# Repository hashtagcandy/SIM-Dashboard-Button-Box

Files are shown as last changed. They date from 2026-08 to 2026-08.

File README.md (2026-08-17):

# ETS2 Sim Button Box

Custom Euro Truck Simulator 2 button box built around a Raspberry Pi Pico H (RP2040).

## Overview

- **Input**: 6x6 switch matrix (12 GPIO) -> ~31 logical controls
- **Output**: 23 indicator LEDs driven by 3x 74HC595 shift registers
- **Interface**: USB Keyboard HID to Windows, bound to ETS2 actions
- **Firmware**: Custom Arduino USB keyboard HID sketch

## Hardware inventory

| Hardware | Qty | Use |
|---|---|---|
| Raspberry Pi Pico H (RP2040) | 1 | Main controller (chosen brain) |
| SmartElex 74HC595 shift register breakout | 3 | LED drivers (24 outputs, 23 used) |
| Pro Micro (Type C, ATmega32U4) | 1 | Spare / test board |
| 3-position rotary selector | 2 | Wipers + Lights |
| Toggle switch | 6 | High beam, beacon, hazard, diff lock, axle, cruise |
| Push/pull switch | 2 | Parking brake, trailer brake |
| Rocker switch | 3 | Windows L/R, cruise speed |
| Latching push button | 3 | Trailer attach, dash mode, audio prev |
| Momentary push button | 5 | Horns, activate, wipers back |
| Ignition key switch | 1 | ACC / ON / START |
| Radio knob (encoder) | 1 | Volume, next favourite |

## Repo layout

```
SOUL.md        Project spec, GPIO map, matrix map, LED map, rules
prerequisites/ Planning docs: key mapping, layout designs, measurements
firmware/      Arduino sketches (Pico H)
docs/          Wiring diagrams, ETS2 bindings, measurement notes
```

## Prerequisites (planning stage)

| File | What it is |
|---|---|
| `prerequisites/01 - key to physical button mapping.md` | All 29 ETS2 functions mapped to physical controls + matrix positions |
| `prerequisites/02 - mapping table.csv` | Same mapping as CSV quick reference |
| `prerequisites/03 - panel layout design.md` | Design principles, LED placement, hole sizes |
| `prerequisites/04 - panel layout diagram.svg` | First layout visual (superseded by A/B/C) |
| `prerequisites/05 - layout A - classic dash.svg` | Layout option A (ignition bottom-left) |
| `prerequisites/06 - layout B - split console.svg` | Layout option B (ignition bottom-right) |
| `prerequisites/07 - layout C - cockpit cluster.svg` | Layout option C (ignition bottom-left) |
| `prerequisites/08 - layout comparison.md` | Compares the three layouts, recommendation |
| `prerequisites/09 - shopping list and BOM.md` | Bill of materials: owned / to buy / tools |
| `prerequisites/10 - keyboard key inventory.md` | Key list, counts, conflicts to fix |
| `prerequisites/11 - matrix design.md` | 6x6 matrix wiring design, scan scheme, ignition re-map |
| `prerequisites/12 - box measurements.md` | Panel size, hole sizes, all hole center coordinates (mm) |
| `prerequisites/13 - drilling template.svg` | Printable 1:1 drilling template with every hole |

## Current status

- [x] Key mapping proposed (29 functions -> physical controls)
- [x] Three panel layout options generated (A/B/C)
- [x] Matrix design drafted (scan scheme, wiring, ignition re-map approved)
- [x] Box measurements + 1:1 drilling template generated (650 x 342 mm panel)
- [ ] Layout chosen by user
- [ ] Panel size / enclosure confirmed
- [ ] Selector & ignition contacts measured with multimeter
- [ ] Firmware development

## Development order

1. USB keyboard test
2. One direct switch
3. 2x2 / four-switch matrix
4. Momentary vs toggle behavior
5. Three-position selector measurement and test
6. Full 6x6 matrix
7. One 74HC595 + 8 LEDs
8. Three 74HC595 + all 23 LEDs
9. Final ETS2 key map
10. Permanent wiring and enclosure

Read `SOUL.md` before changing hardware or firmware. It is the source of truth for pin maps and behavior rules.

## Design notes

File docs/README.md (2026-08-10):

# docs/

Documentation that grows with the project.

Planned:
- `wiring.md` — physical wiring, harness, enclosure notes
- `ets2-bindings.md` — final ETS2 Controls menu key assignments
- `selector-measurements.md` — multimeter results for 3-position selectors and ignition key
- `led-map.md` — final LED numbering / labels once confirmed

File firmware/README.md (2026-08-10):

# firmware/

Arduino sketches for the Raspberry Pi Pico H (RP2040).

Planned sketches, in development order:

1. `usb_keyboard_test/` — verify USB HID enumeration and key output
2. `direct_switch/` — one direct switch (GP2 -> switch -> GND)
3. `matrix_test/` — 2x2 then 6x6 matrix scanning
4. `button_box/` — full firmware: matrix + behaviors + LED chain

Each sketch is a normal Arduino `.ino` folder.

Board setup in Arduino IDE:
- Board: Raspberry Pi Pico (via arduino-pico core: https://github.com/earlephilhower/arduino-pico)
- USB stack: "Pico SDK" (default) — Keyboard works out of the box

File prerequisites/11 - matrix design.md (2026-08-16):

# ETS2 Button Box — Switch Matrix Design

How the 6x6 matrix is wired and scanned. This is the wiring-level design
that turns the logical map (file 01/02) into physical wires on the Pico.

Status: PROPOSAL — no soldering yet. Contains one re-map decision that
needs user approval (section 4).

---

## 1. Scan scheme (how firmware reads switches)

- 6 row GPIO (GP2-GP7) configured as OUTPUT.
- 6 column GPIO (GP8-GP13) configured as INPUT_PULLUP.
- Firmware drives ONE row LOW at a time, reads all 6 columns.
- A closed switch connects row (LOW) to column -> column reads LOW = pressed.
- An open switch leaves the column HIGH (internal pull-up) = not pressed.
- Full matrix scan = 6 row activations x 6 column reads = 36 samples.
- No external pull-up resistors needed: Pico internal pull-ups (~50k ohm)
  are sufficient for a switch matrix.
- Debounce in firmware: re-read after 15-20 ms before accepting a change.

```
          COLUMNS (GP8..GP13, INPUT_PULLUP, LOW = pressed)
          C1    C2    C3    C4    C5    C6
         GP8   GP9   GP10  GP11  GP12  GP13
        +-----+-----+-----+-----+-----+-----+
R1 GP2  | W1  | W2  | W3  | L1  | L2  | L3  |  selectors (3-pos)
R2 GP3  | HB  | BEA | HAZ | DIF | AXL | CRU |  6 toggles
R3 GP4  | PK  | TRL | ATT | NXT | PRV | HRN |  push/pull + latching
R4 GP5  | AH  | LH  | DSH | ACT | WLU | WLD |  momentaries + rocker 1
R5 GP6  | WRU | WRD | CR+ | CR- | INF | SP  |  rocker 2 + cruise + infomaint
R6 GP7  | ST  | ACC | ON  | RAD+| RAD-| RDP |  ignition + radio
        +-----+-----+-----+-----+-----+-----+
        ROWS = OUTPUT, driven LOW one at a time
```

Legend:

| Label | Function | Key | Label | Function | Key |
|---|---|---|---|---|---|
| W1-3 | Wipers pos 1/2/3 | P | WRU | Open Right Window | W |
| L1-3 | Light pos 1/2/3 | L | WRD | Close Right Window | S |
| HB | High Beam | K | CR+ | Cruise speed + | = |
| BEA | Beacon | U | CR- | Cruise speed - | - |
| HAZ | Hazard | F | INF | Infomaint display | G |
| DIF | Diff Lock | D | ST | Ignition START | E |
| AXL | Lift/Drop Axle | J | ACC | Ignition ACC | Shift+E |
| CRU | Cruise Control | C | ON | Ignition ON | E |
| PK | Parking Brake | SPACE | RAD+ | Volume Up | + |
| TRL | Trailer Brake | 7 | RAD- | Volume Down | 8 |
| ATT | Trailer Attach | T | RDP | pause/play | 9 |
| NXT | Audio Next | N | SP | spare | - |
| PRV | Audio Previous | 0 | | | |
| HRN | Horn | H | | | |
| AH | Air Horn | V | | | |
| LH | Light Horn | B | | | |
| DSH | Dashboard Mode | I | | | |
| ACT | Activate | ENTER | | | |
| WLU | Open Left Window | Q | | | |
| WLD | Close Left Window | A | | | |

Keys shown are the RESOLVED map from file 10 (conflicts already fixed).

---

## 2. Wiring per control type

Each switch is wired as: ROW wire -> one lug, COLUMN wire -> other lug.

| Control | Lugs to use | Wiring |
|---|---|---|
| Toggle switch | 2 (common + ON lug) | common -> row, ON lug -> column |
| Push/pull switch | 2 | one side -> row, other side -> column |
| Momentary button | 2 | one terminal -> row, other -> column |
| Latching button | 2 | one terminal -> row, other -> column |
| Rocker (center-off) | 3 | common -> row, UP lug -> column A, DOWN lug -> column B |
| 3-position selector | 4 | common -> row, 3 state lugs -> 3 columns (MUST measure first) |
| EC11 encoder | 5 | common -> row, A -> column CW, B -> column CCW, push -> column |
| Ignition key | 4+ | common (B) -> row, ACC -> column, ON/IGN -> column, ST -> column (MUST measure first) |

### Encoder detail (EC11)

Typical EC11 has 5 pins: A, B, C (common), plus 2 for the push switch.

```
EC11            Matrix
A    ---------> column (CW detent)
B    ---------> column (CCW detent)
C    ---------> row (shared)
push ---------> column (tap on press)
```

Firmware decodes quadrature (A/B order) to decide CW vs CCW, one key tap
per detent. The push is just another switch on the same row.

### Selector detail

Both 3-position selectors occupy one full row each:

```
Selector (4 terminals)          Matrix
common lug  ----------------> R1
state lug 1 (position 1) ----> C1 / C4
state lug 2 (position 2) ----> C2 / C5
state lug 3 (position 3) ----> C3 / C6
```

Wiper selector: R1C1/R1C2/R1C3. Light selector: R1C4/R1C5/R1C6.

CONTACTS MUST BE MEASURED WITH A MULTIMETER — terminal numbers alone do
not tell you which lug is common or which is position 1/2/3.

---

## 3. Wire plan / color code

Keep 12 matrix wires traceable:

| Wire | Color | Notes |
|---|---|---|
| Rows R1-R6 | RED | tag each wire R1..R6 (heat-shrink label or tape) |
| Columns C1-C6 | BLUE | tag each wire C1..C6 |
| Common GND | BLACK | not used by matrix itself |

Each switch gets exactly two wires: one red (to its row), one blue (to
its column). Multi-position controls (rockers, selectors, encoders,
ignition) share one red wire on the common lug and one blue per column.

Wiring groups (nice for routing):

| Row | Controls sharing the row wire |
|---|---|
| R1 | Wiper selector common + Light selector common |
| R2 | 6 toggle commons |
| R3 | 2 push/pull + 3 latching + horn |
| R4 | 3 momentaries + activate + rocker 1 common |
| R5 | rocker 2 common + cruise encoder common + infomaint |
| R6 | ignition common + radio encoder common |

---

## 4. RE-MAP DECISION — ignition key needs one row (PENDING APPROVAL)

PROBLEM: the current mapping (files 01/02) puts Ignition ACC and ON on
row 5 but START on row 6. A typical ignition key switch has ONE common
lug (Battery). ACC, ON and START all share it, so they must all sit on
the SAME row. Splitting them across R5 and R6 is not physically wireable
with a single-common key.

FIX: move the whole ignition key to row 6, and slide the radio encoder
over to make room. Infomaint moves up to row 5's freed space.

| Position | OLD mapping | NEW mapping |
|---|---|---|
| R5C1 | Rocker 2 up | Rocker 2 up (unchanged) |
| R5C2 | Rocker 2 down | Rocker 2 down (unchanged) |
| R5C3 | Cruise CW | Cruise CW (unchanged) |
| R5C4 | Cruise CCW | Cruise CCW (unchanged) |
| R5C5 | Ignition ACC | **Infomaint** (moved from R6C5) |
| R5C6 | Ignition ON | **spare** (moved from R6C6) |
| R6C1 | Ignition START | Ignition START (unchanged) |
| R6C2 | Radio CW | **Ignition ACC** (moved from R5C5) |
| R6C3 | Radio CCW | **Ignition ON** (moved from R5C6) |
| R6C4 | Radio push | **Radio CW** (moved from R6C2) |
| R6C5 | Infomaint | **Radio CCW** (moved from R6C3) |
| R6C6 | spare | **Radio push** (moved from R6C4) |

Result: ignition = R6C1 (ST) / R6C2 (ACC) / R6C3 (ON), all sharing row 6.
Radio = R6C4/C5/C6, also sharing row 6. Rocker 2 + cruise + infomaint
keep row 5 to themselves. All 36 positions still used, zero new hardware.

If the multimeter later shows the ignition key has SEPARATE commons per
position (rare), the old split could work — but plan for single-common.

IF APPROVED: update `02 - mapping table.csv`, the tables in
`01 - key to physical button mapping.md`, and SOUL.md matrix map together.

---

## 5. Test plan (matrix bring-up)

1. Breadboard a 2x2 mini matrix (2 rows, 2 cols, 4 momentary buttons).
   Verify scan: press each button, confirm correct R/C detected.
2. Test simultaneous presses on the mini matrix (ghosting check).
   Matrix diodes were skipped by decision — confirm no ghosting at 2x2.
3. Build the full 6x6 on breadboard with all switch types (toggle,
   push/pull, rocker, latching, momentary, selectors, encoders, ignition).
4. Test every one of the 36 positions individually (LED or serial print).
5. Test multi-press patterns that would have ghosted before wiring permanent.
6. If ghosting appears: add one 1N4148 diode per switch (36 max), cathode
   toward the column.

---

## 6. Open questions before wiring

1. Ignition key contact layout — single common or separate per position?
   Multimeter: find common, then map ACC/ON/START lugs.
2. Selector contact layout — which lug is common, which is pos 1/2/3?
   Multimeter on all 4 lugs in all 3 positions.
3. Rocker switch type — confirm 3-terminal center-off (common + up + down).
4. EC11 encoder pinout — confirm A/B/common/push pins on the actual part.

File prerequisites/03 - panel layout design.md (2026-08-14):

# ETS2 Button Box — Panel Layout Design (v1 PROPOSAL)

Reference: prerequisites/01 - key to physical button mapping.md

## 1. Design principles

1. Group by truck function: lights together, brakes together, audio together.
2. Frequent / emergency controls closest to the user (front edge of panel):
   horns + activate.
3. Parking brake gets a prominent position — it is the most-grabbed control
   in a truck.
4. Every stateful control gets an LED right next to it (state at a glance).
5. 3-position selectors get a 3-LED position strip, like a real dash indicator.
6. Ignition key sits in a corner — the "start of the day" control, away from
   controls you touch while driving.

## 2. Default panel size assumption

Landscape panel, approx 300 x 170 mm (can be resized — nothing is cut yet).

Controls are laid out in 6 horizontal rows. Row 5 (momentary buttons) is the
front edge (closest to the user).

## 3. The layout (driver's view, top = far edge)

```
+------------------------------------------------------------------+
|  [IGN]    [WIPER  o o o]   [LIGHT  o o o]             [RADIO]   |
|  KEY      0  1  2           0  1  2                              |
|                                                                  |
|   o   o   o       o   o   o                                      |
|  [HB] [BEA] [HAZ] | [DIFF] [AXLE] [CRUISE]   <- 6 toggles       |
|                                                                  |
|   o                    o                                         |
|  [PARK BRAKE]       [TRAILER BRAKE]          <- 2 push/pull      |
|    (pull handle)      (pull handle)                              |
|                                                                  |
|  [WIN L]   [WIN R]   [CRUISE +/-]            <- 3 rockers       |
|   up/down   up/down   inc/dec                                    |
|                                                                  |
|   o   o   o       o   o                                          |
|  [HORN] [AIR] [LT HORN]  [ACT] [WIPER BACK]  <- 5 momentary     |
|                                                                  |
|   o   o   o                                                      |
|  [TRAILER ATT] [DASH MODE] [AUD PREV]        <- 3 latching      |
|                                                                  |
|                 ^                                                |
|                 front edge (closest to user)                     |
+------------------------------------------------------------------+
```

o = indicator LED next to the control

## 4. LED placement

| LED | Location |
|---|---|
| Wiper pos 1/2/3 | 3-LED strip directly above wiper selector |
| Light pos 1/2/3 | 3-LED strip directly above light selector |
| High beam | above toggle 1 |
| Beacon | above toggle 2 |
| Hazard | above toggle 3 |
| Diff lock | above toggle 4 |
| Lift/Drop axle | above toggle 5 |
| Cruise control | above toggle 6 |
| Park brake | beside park brake handle |
| Trailer brake | beside trailer brake handle |
| Trailer attach | beside latching 1 |
| Dash mode | beside latching 2 |
| Audio prev | beside latching 3 |
| Horn | beside momentary 1 |
| Air horn | beside momentary 2 |
| Light horn | beside momentary 3 |
| Activate | beside momentary 4 |
| Wipers back | beside momentary 5 |
| Ignition | beside ignition key (lights with ACC/ON state) |

Total: 23 LEDs = exactly the 3x 74HC595 capacity (24 outputs, 1 spare).

## 5. Mounting hole sizes (typical)

| Control | Hole / cutout |
|---|---|
| 3-position rotary selector | 20 mm round |
| Toggle switch | 12 mm round |
| Push/pull switch | 12 mm round |
| Rocker switch | 19 x 13 mm rectangle |
| Latching push button | 12 mm round (16 mm if LED-ring type) |
| Momentary push button | 12 mm round (16 mm if LED-ring type) |
| Ignition key switch | 19-22 mm round |
| Radio encoder | 10 mm round (6 mm shaft + nut) |
| Indicator LED (5 mm) | 5 mm round |

Spacing rule: minimum 25 mm center-to-center between adjacent controls,
so fingers/knobs never collide. If the panel is larger, add 30 mm.

## 6. Wiring implications

- All controls stay in the 6x6 matrix — layout does not change the matrix map.
- LED order in the 74HC595 chain follows the LED table above (LED #1 =
  wiper pos 1 ... LED #23 = ignition). See SOUL.md LED numbering.
- The push/pull brake handles and rockers are mounted so "pull" and "up"
  are clearly labelled — add laser-printed or engraved labels on the panel.

## 7. Open questions

1. Actual enclosure size / panel dimensions? (adjust row spacing)
2. Do the momentary buttons have LED rings, or plain? (affects LED count)
3. Material: 3D printed, acrylic, aluminium, or wood?
4. Labels: engraved, printed sticker, or painted?
5. Do you want the ignition key on the LEFT (current) or RIGHT corner?

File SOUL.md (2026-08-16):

# SOUL.md — DIY ETS2 Sim Button Box

## Project identity

This is a custom **Euro Truck Simulator 2 (ETS2) sim button box** built around a **Raspberry Pi Pico H / RP2040**.

Primary goals:
- USB keyboard HID output to Windows.
- ETS2 controls assigned to keyboard keys.
- Use a switch matrix so GPIO is not exhausted.
- Use 74HC595 shift registers for indicator LEDs.
- Toggle/latching controls send **one key tap per state change**, not a continuously held/repeating key.
- Momentary controls can behave as true held keys.
- Three-position selectors report their actual selected state.
- Keep hardware, GPIO mapping, firmware behavior, and ETS2 mapping documented.

---

## Current hardware

### Controller
- Raspberry Pi Pico H / RP2040
- Male headers are already soldered.
- Arduino IDE is being used.
- Planned firmware: custom Arduino USB keyboard HID.
- GP2040-CE was tested, but the project is moving to keyboard firmware.
- BOOTSEL is the Pico bootloader button, not an ordinary GPIO input.

### Confirmed tests
- Direct switch: `GP2 -> switch -> GND` works.
- GP3 also works.
- GP0/GP1 are not permanently unusable hardware pins; they are ordinary RP2040 GPIOs, but this project intentionally leaves them unused for simplicity.
- GP25 is the Pico onboard LED GPIO and is intentionally left unused in the main matrix.

---

## Physical control inventory

| Hardware | Quantity | Logical inputs |
|---|---:|---:|
| 3-position rotary selector | 2 | 3 states each; exact electrical encoding must be measured |
| Latching push button | 3 | 3 |
| Momentary push button | 5 | 5 |
| Toggle switch | 6 | 6 |
| Push/pull switch | 2 | 2 |
| Rocker switch | 3 | 6 if both directions are independently used |
| Ignition key | 1 | up to 3 contacts/states |
| Radio knob/encoder | 1 | normally 2 encoder signals; add one more input if it has push-to-click |
| **Approximate total** | | **~31 logical inputs** |

The exact ignition and 3-position selector contacts must be verified with a multimeter before final wiring.

---

## Indicator LEDs

Planned LEDs:

| Control | LEDs |
|---|---:|
| Wiper 3-position selector | 3 |
| Light 3-position selector | 3 |
| Six toggle switches | 6 |
| Two push/pull switches | 2 |
| Ignition key | 1 |
| Eight push buttons | 8 |
| Rockers | 0 |
| Radio knob | 0 |
| **Total** | **23** |

LEDs are from the user's assorted 5 mm LED kit.

### LED rule

A bare 5 mm LED needs its own current-limiting resistor.

Starting value:

`330 ohm per LED`

Do not share one resistor between independent LEDs.

Basic wiring:

```text
74HC595 output -> 330R -> LED anode
LED cathode -> GND
```

---

# Input architecture — 6x6 matrix

A 6x6 matrix gives:

```text
6 rows + 6 columns = 12 GPIO
6 x 6 = 36 matrix positions
```

The project needs 31 logical switch positions; the matrix provides 36,
so one spare position remains (R5C6).

### Matrix rule

Each switch connects a row to a column:

```text
ROW GPIO ---- SWITCH ---- COLUMN GPIO
```

Matrix switches do **not** connect directly to GND.

The firmware scans one row at a time and reads the columns.

### Important ghosting note

A bare switch matrix can suffer from ghosting/masking when multiple switches are pressed simultaneously. This may matter in a sim panel where several controls can be active.

If ghosting occurs, add one diode per matrix switch (commonly 1N4148) and implement diode-aware scanning. Do not assume a bare matrix is automatically ghost-free.

DECISION (recorded): initial build will use a bare matrix with NO diodes. The user does not expect to press many switches simultaneously. If ghosting appears in testing, add diodes later (one per switch, 36 max).

---

# Pico GPIO map

## Matrix rows

| GPIO | Assignment |
|---|---|
| GP2 | Row 1 |
| GP3 | Row 2 |
| GP4 | Row 3 |
| GP5 | Row 4 |
| GP6 | Row 5 |
| GP7 | Row 6 |

## Matrix columns

| GPIO | Assignment |
|---|---|
| GP8 | Column 1 |
| GP9 | Column 2 |
| GP10 | Column 3 |
| GP11 | Column 4 |
| GP12 | Column 5 |
| GP13 | Column 6 |

This consumes 12 GPIO.

---

# Logical matrix map

This is the proposed starting map. It should be treated as a logical map until the user confirms the final physical layout.

| Matrix | Function |
|---|---|
| R1C1 | Wiper position 1 |
| R1C2 | Wiper position 2 |
| R1C3 | Wiper position 3 |
| R1C4 | Lights position 1 |
| R1C5 | Lights position 2 |
| R1C6 | Lights position 3 |
| R2C1 | Toggle 1 High Beam |
| R2C2 | Toggle 2 Beacon |
| R2C3 | Toggle 3 Hazard Warning |
| R2C4 | Toggle 4 Differential Lock |
| R2C5 | Toggle 5 Lift / Drop Axle |
| R2C6 | Toggle 6 Cruise Control |
| R3C1 | Push/pull 1 Parking Brake |
| R3C2 | Push/pull 2 Trailer Brake |
| R3C3 | Momentary 6 Trailer Attach (latching body) |
| R3C4 | Momentary 7 Audio Next (latching body) |
| R3C5 | Momentary 8 Audio Previous (latching body) |
| R3C6 | Momentary 1 Horn |
| R4C1 | Momentary 2 Air Horn |
| R4C2 | Momentary 3 Light Horn |
| R4C3 | Momentary 4 Dashboard Display |
| R4C4 | Momentary 5 Activate |
| R4C5 | Rocker 1 up Open Left Window |
| R4C6 | Rocker 1 down Close Left Window |
| R5C1 | Rocker 2 up Open Right Window |
| R5C2 | Rocker 2 down Close Right Window |
| R5C3 | Cruise knob CW (speed +) |
| R5C4 | Cruise knob CCW (speed -) |
| R5C5 | Momentary 9 Infomaint display |
| R5C6 | Spare |
| R6C1 | Ignition START |
| R6C2 | Ignition ACC |
| R6C3 | Ignition ON |
| R6C4 | Radio knob CW (volume +) |
| R6C5 | Radio knob CCW (volume -) |
| R6C6 | Radio knob push (pause/play) |

IGNITION NOTE: ACC, ON and START all sit on row 6 because a typical
ignition key has ONE common lug shared by all positions — it can only
wire to one row. Do not split the ignition across rows (see
`prerequisites/11 - matrix design.md`).

### Three-position selector warning

The user's selector has four screw terminals. Do not assume the terminal numbers alone tell us the three states.

Before firmware mapping, measure:

```text
LEFT   -> connected contacts
CENTER -> connected contacts
RIGHT  -> connected contacts
```

Then map those actual combinations.

---

# Switch behavior

## Momentary

Desired:

```text
pressed  -> Keyboard.press(key)
released -> Keyboard.release(key)
```

Useful for controls where holding the key matters, such as a horn if desired.

## Toggle/latching

Desired:

```text
OFF -> ON  : send one key tap
ON  -> OFF : send one key tap
```

Do **not** continuously call `Keyboard.press()` for a toggle.

Use state-change detection and:

```cpp
Keyboard.write(key);
```

once per transition.

Example:

```text
Toggle ON:
H

Toggle stays ON:
nothing

Toggle OFF:
H
```

This prevents `HHHHHHHHHH...` or similar repeated characters.

## Push/pull

Treat according to the ETS2 function:
- state-based function -> one tap on state change
- hold-based function -> press/release

## Three-position selector

Treat it as a mutually exclusive state machine:

```text
LEFT
CENTER
RIGHT
```

Send a command only when the selected state changes.

---

# LED architecture — 74HC595

23 LEDs are planned.

Use:

```text
3 x 74HC595
```

Each provides 8 outputs:

```text
3 x 8 = 24 outputs
```

So 23 LEDs fit with one spare output.

## Pico -> 74HC595

Proposed:

```text
GP14 -> DATA / SER
GP15 -> CLOCK / SRCLK
GP16 -> LATCH / RCLK
```

Shared by all three chips:

```text
CLOCK
LATCH
VCC
GND
```

Serial chain:

```text
Pico DATA
   |
   v
595 #1 -> 595 #2 -> 595 #3
          Q7'       Q7'
```

Q7' of each chip goes to SER of the next chip.

### Power

```text
VCC  -> 3.3 V
GND  -> common GND
OE   -> GND
SRCLR -> 3.3 V
```

Add a 0.1 uF ceramic decoupling capacitor close to each 74HC595 if available.

### Current

The 74HC595 is not a high-current LED driver. Keep LED current conservative. Around 2–5 mA per indicator is a good starting point. If many LEDs must be very bright simultaneously, use a dedicated LED driver or transistor stage instead of heavily loading the 74HC595.

---

# LED numbering

Suggested firmware numbering:

| LED # | Function |
|---:|---|
| 1 | Wiper LEFT |
| 2 | Wiper CENTER |
| 3 | Wiper RIGHT |
| 4 | Lights state 1 |
| 5 | Lights state 2 |
| 6 | Lights state 3 |
| 7 | Toggle 1 |
| 8 | Toggle 2 |
| 9 | Toggle 3 |
| 10 | Toggle 4 |
| 11 | Toggle 5 |
| 12 | Toggle 6 |
| 13 | Park brake |
| 14 | Trailer air |
| 15 | Latching push 1 |
| 16 | Latching push 2 |
| 17 | Latching push 3 |
| 18 | Momentary push 1 |
| 19 | Momentary push 2 |
| 20 | Momentary push 3 |
| 21 | Momentary push 4 |
| 22 | Momentary push 5 |
| 23 | Ignition |

Exact labels can be finalized later.

---

# Ground distribution

Use a common ground bus/terminal block for:

- Pico GND
- 74HC595 GND
- LED cathodes
- other low-voltage ground-referenced circuits

However:

**Matrix switch contacts do not connect to the common GND bus.**

Matrix:

```text
ROW -> switch -> COLUMN
```

LED:

```text
74HC595 -> resistor -> LED -> GND
```

---

# USB keyboard firmware

The firmware is custom Arduino code for RP2040 USB HID.

The software must separate:

### Momentary

```text
pressed  -> key down
released -> key up
```

### Toggle/latching

```text
state changed -> one Keyboard.write()
```

### Selector

```text
state changed -> command for the new state
```

Never repeatedly emit a keyboard key just because a latching switch remains ON.

---

# ETS2 key-binding philosophy

Do not treat old/default keyboard assignments as immutable.

ETS2 supports customizable keyboard/controller bindings and advanced input configuration. Its official input documentation describes `controls.sii`, controller inputs, keyboard inputs, mixes, and selector-dependent configurations.

The firmware should therefore have a user-editable key map.

A commonly documented ETS2-style starting point is:

| Function | Common key |
|---|---|
| Engine start/stop | E |
| Parking brake | SPACE |
| Engine brake | B |
| Lights mode | L |
| High beam | K |
| Horn | H |
| Wipers | P |
| Cruise control | C |
| Dashboard display mode | I |
| Trailer connect/disconnect | T |
| World map | M |
| Radio/audio player | R |
| Left indicator | [ |
| Right indicator | ] |
| Hazard lights | F |

These are a starting point only. The user's current ETS2 profile should be treated as the source of truth.

ETS2 also supports more advanced custom input configuration in `controls.sii`.

---

# Suggested physical control functions

## 3-position selectors

### WIPER
Potential states:
- OFF/intermittent
- normal
- fast

The exact ETS2 commands available should be verified in the current Controls menu.

### LIGHT
Potential states:
- OFF/position
- low/normal
- high/main

Verify the exact current ETS2 actions before final firmware.

## Toggles

Planned examples:
- High beam
- AUX
- Beacon
- additional truck functions

Remaining toggle assignments should be finalized from the user's intended ETS2 functions.

## Push/pull

- Parking brake
- Trailer air / trailer-related function

## Push buttons

Planned functions include:
- Horn
- Cruise
- Activate
- Display information
- Dashboard
- additional functions to be finalized

## Rockers

Planned functions include:
- Window left/right
- Retarder
- Differential lock

## Ignition

Physical states:

```text
ACC
IGN
START
```

Exact contacts must be measured.

## Radio knob

Planned behavior:

```text
turn left  -> volume down
turn right -> volume up
press      -> play/pause
```

If the encoder has a push switch, reserve one additional matrix position.

---

# Development order

1. **USB keyboard test**
2. **One direct switch**
3. **2x2 / four-switch matrix**
4. **Momentary vs toggle behavior**
5. **Three-position selector measurement and test**
6. **Full 6x6 matrix**
7. **One 74HC595 + 8 LEDs**
8. **Three 74HC595 + all 23 LEDs**
9. **Final ETS2 key map**
10. **Permanent wiring and enclosure**

Do not permanently mount or solder everything until each stage works.

---

# Debugging rules

### Random keyboard characters
Check:
- floating inputs
- pull-up/pull-down configuration
- row/column scanning
- incorrect switch wiring
- debounce
- unintended simultaneous keys

### Toggle repeats
Firmware is probably holding the key.

Use transition detection + `Keyboard.write()`.

### Matrix ghosting
If multiple switches create a false key:
- add per-switch diodes
- verify scan direction
- verify inactive rows are in a safe state
- verify the firmware scans only one active row at a time

### LED problems
Check:
- common GND
- 74HC595 VCC
- OE
- SRCLR
- clock
- latch
- serial chain
- resistor per LED
- decoupling capacitors

### Selector position wrong
Measure the selector with a multimeter before changing firmware.

---

# Current project status

Confirmed:
- Pico H works.
- USB works.
- GP2040-CE was tested.
- GP2 works as an input.
- GP3 works as an input.
- Direct switch wiring works.
- Project direction is Arduino USB keyboard firmware.
- 6x6 switch matrix selected.
- 3 x 74HC595 selected for LEDs.
- 23 indicator LEDs planned.

Not yet finalized:
- exact physical-to-matrix mapping
- exact 3-position selector contact mapping
- final ETS2 key assignments
- LED current/brightness
- whether matrix diodes are required
- exact encoder wiring
- final permanent harness

---

# Rules for future development

1. Do not change the matrix architecture without a specific reason.
2. Measure the 3-position selector; never infer its contacts.
3. A toggle is not a held keyboard key.
4. Separate momentary, toggle, and selector logic.
5. Every bare LED gets its own resistor.
6. Do not overload 74HC595 outputs.
7. Matrix switches do not connect directly to the common GND bus.
8. Keep the GPIO map stable once physical wiring starts.
9. Test small circuits before expanding.
10. Keep ETS2 key assignments editable.
11. Do not assume community/default ETS2 bindings are unchanged.
12. Update this file before major hardware changes.
13. When changing a pin, update both the pin map and firmware.
14. Do not permanently install a component until its electrical behavior has been tested.

---

# Primary objective

The final device should behave like a purpose-built truck dashboard:

```text
Physical switch
      |
      v
6x6 matrix
      |
      v
RP2040
      |
      +---- USB Keyboard HID ----> Windows ----> ETS2
      |
      +---- 74HC595 chain ----> 23 indicator LEDs
```

Target behavior:

```text
Momentary = hold/release
Toggle    = one tap per state change
Selector  = explicit state
Encoder   = directional events
LED       = physical state indication
```

The objective is not merely to make every switch output a key. The objective is to make the panel behave like a coherent ETS2 truck control console.

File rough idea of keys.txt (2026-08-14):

Start / Stop Engine
Start / Stop Engine Electricity
Parking Brake
Trailer Brake
Lift / Drop Axle
Differential Lock
Hazard Warning
Light Modes
High Beam Headlights
Beacon
Horn
Air Horn
Light Horn
Wipers
Wipers Back
Cruise Control
Cruise Control Speed Increase
Cruise Control Speed Decrease
Dashboard Display Mode
Open Right Window
Close Right Window
Open Left Window
Close Left Window
Activate
Trailer Attach / Detach
Audio Player Volume Up
Audio Player Volume Down
Audio Player next
Audio Player Previous
audio pause play
Infomaint display mode

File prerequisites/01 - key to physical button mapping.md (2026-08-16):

# ETS2 Button Box — Key to Physical Button Mapping

Source file: `rough idea of keys.txt` (31 functions)
Control names verified against: `ATS and ETS2 Key Bindings.xlsx`

Status: PROPOSAL — nothing is soldered yet. Keys below are the ACTUAL
keys the user will use (from `02 - mapping table.csv`). Verify keys in
the ETS2 Controls menu before finalizing; any change must be made in
`02 - mapping table.csv` first, then this file.

---

## 1. Physical controls available

| # | Control | Qty | Notes |
|---|---|---|---|
| A | 3-position rotary selector | 2 | Wiper + Lights (3 states each) |
| B | Toggle switch (on/off) | 6 | stays in position |
| C | Push/pull switch | 2 | pull = on, push = off |
| D | Rocker switch | 3 | spring back to center, 2 directions (only 2 used) |
| E | Latching push button | 3 | stays in when pressed; used as momentary-style (one tap per press) |
| F | Momentary push button | 5 + 2 NEW | returns when released |
| G | Ignition key switch | 1 | OFF / ACC / ON (+START if present) |
| H | Radio knob / encoder (EC11 with push) | 1 | rotate CW/CCW + push |
| I | Cruise knob / encoder (EC11) | 1 | rotate CW/CCW for cruise speed (+push optional) |

Total matrix positions used: 36 of 36 (full matrix — no spares left).

---

## 2. The mapping

### Selectors (3-position, one tap per state change)

All three positions send the same cycle key; firmware counts taps to
reach the selected state (off->normal = 1 tap, off->fast = 2 taps,
fast->off = 3 taps, etc.).

| Matrix | Control | ETS2 function | Key | Behavior |
|---|---|---|---|---|
| R1C1 | Wiper selector pos 1 | Wipers OFF | P | tap key to reach OFF |
| R1C2 | Wiper selector pos 2 | Wipers NORMAL | P | tap key to reach NORMAL |
| R1C3 | Wiper selector pos 3 | Wipers FAST | P | tap key to reach FAST |
| R1C4 | Light selector pos 1 | Lights OFF | L | tap key to reach OFF |
| R1C5 | Light selector pos 2 | Lights PARKING | L | tap key to reach PARKING |
| R1C6 | Light selector pos 3 | Lights LOW BEAM | L | tap key to reach LOW BEAM |

NOTE: ETS2 "Wipers" and "Light Modes" are CYCLE keys (one press = next
state). Firmware must count taps: off->normal = 1 tap, off->fast = 2 taps,
fast->off = 3 taps, etc. The box tracks the last known state, so the
physical knob always lands on the same in-game state.

WIPERS BACK: assigned to the wiper selector's spring-back "negative"
position (if the selector has one). If it does not, Wipers Back needs its
own momentary button — see open question 5.

### Toggles (6) — one tap per state change

| Matrix | Control | ETS2 function | Key | Verify |
|---|---|---|---|---|
| R2C1 | Toggle 1 | High Beam Headlights | K | yes |
| R2C2 | Toggle 2 | Beacon | U | yes |
| R2C3 | Toggle 3 | Hazard Warning | F | yes |
| R2C4 | Toggle 4 | Differential Lock | D | yes |
| R2C5 | Toggle 5 | Lift / Drop Axle | J | yes |
| R2C6 | Toggle 6 | Cruise Control | C | yes |

Cruise Control is ON/OFF via Toggle 6. Speed is adjusted with the
cruise knob below.

### Push/pull (2) — one tap per state change

| Matrix | Control | ETS2 function | Key | Verify |
|---|---|---|---|---|
| R3C1 | Push/pull 1 | Parking Brake | SPACE | yes |
| R3C2 | Push/pull 2 | Trailer Brake | 7 | yes |

### Momentary (9 used of 10) — one tap per press

All momentary-style: press = one tap of the key. Functions that ETS2
treats as "press to toggle/cycle" fit this perfectly.

| Matrix | Control | ETS2 function | Key | Verify |
|---|---|---|---|---|
| R3C6 | Momentary 1 | Horn | H | yes |
| R4C1 | Momentary 2 | Air Horn | V | yes |
| R4C2 | Momentary 3 | Light Horn | B | yes |
| R4C3 | Momentary 4 | Dashboard Display Mode | I | yes |
| R4C4 | Momentary 5 | Activate | ENTER | yes |
| R3C3 | Momentary 6 | Trailer Attach / Detach | T | yes |
| R3C4 | Momentary 7 | Audio Player Next | N | yes |
| R3C5 | Momentary 8 | Audio Player Previous | P | yes |
| R5C5 | Momentary 9 | Infomaint display mode | I | yes |
| R5C6 | Momentary 10 | (spare) | - | - |

NOTE: Momentary 6/7/8 use the physical buttons originally bought as
"latching" — they are simply treated as momentary-style in firmware
(one tap per press, ignore the latching state). No extra purchases
beyond the 2 new buttons.

NOTE: Momentary 8 (P) and Momentary 4 (I) share keys with the Wipers (P)
and Infomaint (I) — see the 5 conflicts in `10 - keyboard key inventory.md`.
The firmware must be built with the RESOLVED key map, not this raw list.

### Rockers (2 of 3 used) — hold while pressed

| Matrix | Control | ETS2 function | Key | Verify |
|---|---|---|---|---|
| R4C5 | Rocker 1 up | Open Left Window | Q | yes |
| R4C6 | Rocker 1 down | Close Left Window | A | yes |
| R5C1 | Rocker 2 up | Open Right Window | W | yes |
| R5C2 | Rocker 2 down | Close Right Window | S | yes |

Rocker 3 (R5C3/R5C4) is no longer used for cruise speed — replaced by
the cruise knob. The rocker itself becomes a spare physical control.

### Cruise knob (encoder) — like a second volume knob

| Matrix | Control | ETS2 function | Key | Behavior |
|---|---|---|---|---|
| R5C3 | Cruise knob CW | Cruise Control Speed Increase | = | one tap per detent |
| R5C4 | Cruise knob CCW | Cruise Control Speed Decrease | - | one tap per detent |

Optional: if the cruise knob also has a push, use it for Cruise Control
Resume (position R5C3 or a spare if the matrix frees up).

### Ignition key (3 positions)

| Matrix | Control | ETS2 function | Key | Behavior |
|---|---|---|---|---|
| R6C1 | Key START | (engine crank, if present) | E | momentary |
| R6C2 | Key ACC | Start / Stop Engine Electricity | E | tap on entering ACC |
| R6C3 | Key ON | Start / Stop Engine | E | tap on entering ON |

NOTE: all three ignition positions send E (ETS2 ignition sequence:
press E = electricity, press again = engine). See the E/E conflict in
`10 - keyboard key inventory.md`.

NOTE: ACC, ON and START all sit on row 6 so the ignition key's single
common lug can wire to one row (see `11 - matrix design.md`).

### Radio knob (encoder with push)

| Matrix | Control | ETS2 function | Key | Behavior |
|---|---|---|---|---|
| R6C4 | Knob CW | Audio Player Volume Up | + | one tap per detent |
| R6C5 | Knob CCW | Audio Player Volume Down | - | one tap per detent |
| R6C6 | Knob push | Audio Player pause/play | SPACE | tap on press (if push exists) |

NOTE: SPACE (pause/play) conflicts with Parking Brake (SPACE) — see the
5 conflicts in `10 - keyboard key inventory.md`.

---

## 3. Function coverage check

All 31 keys.txt functions are covered:

- Start / Stop Engine .................... Ignition key ON (E)
- Start / Stop Engine Electricity ........ Ignition key ACC (E)
- Parking Brake .......................... Push/pull 1 (SPACE)
- Trailer Brake .......................... Push/pull 2 (7)
- Lift / Drop Axle ....................... Toggle 5 (J)
- Differential Lock ...................... Toggle 4 (D)
- Hazard Warning ......................... Toggle 3 (F)
- Light Modes ............................ Light selector (L, 3 pos)
- High Beam Headlights ................... Toggle 1 (K)
- Beacon ................................. Toggle 2 (U)
- Horn ................................... Momentary 1 (H)
- Air Horn ............................... Momentary 2 (V)
- Light Horn ............................. Momentary 3 (B)
- Wipers ................................. Wiper selector (P, 3 pos)
- Wipers Back ............................ Wiper selector negative (or own button)
- Cruise Control ......................... Toggle 6 (C)
- Cruise Control Speed Increase .......... Cruise knob CW (=)
- Cruise Control Speed Decrease .......... Cruise knob CCW (-)
- Dashboard Display Mode ................. Momentary 4 (I)
- Open Right Window ...................... Rocker 2 up (W)
- Close Right Window ..................... Rocker 2 down (S)
- Open Left Window ....................... Rocker 1 up (Q)
- Close Left Window ...................... Rocker 1 down (A)
- Activate ............................... Momentary 5 (ENTER)
- Trailer Attach / Detach ................ Momentary 6 (T)
- Audio Player Volume Up ................. Radio knob CW (+)
- Audio Player Volume Down ............... Radio knob CCW (-)
- Audio Player Next ...................... Momentary 7 (N)
- Audio Player Previous .................. Momentary 8 (P)
- Audio Player pause/play ................ Radio knob push (SPACE)
- Infomaint display mode ................. Momentary 9 (I)

CONFLICT NOTE: 5 keys are currently shared between two functions
(P = Wipers/Audio Previous, SPACE = Parking Brake/pause-play,
I = Dashboard/Infomaint, - = Cruise Decrease/Volume Down,
E = Electricity/Engine Start). See `10 - keyboard key inventory.md`
for the resolved final key map (0, 9, G, 8, Shift+E).

---

## 4. Suggested panel layout (rough)

```
+----------------------------------------------------------+
| [IGN KEY]   [WIPER 0-1-2]        [LIGHT 0-1-2]           |
|                                                          |
| [HB][BEA][HAZ]  [DIFF][AXLE][CRUISE]    <- 6 toggles    |
|                                                          |
| [PARK BRAKE PULL]  [TRAILER BRAKE PULL]  <- push/pull   |
|                                                          |
| [HORN][AIR][LIGHT HORN] [ACTIVATE][AUD NEXT]             |
|                                                          |
| [WIN L UP/DN]  [WIN R UP/DN]   [CRUISE KNOB]            |
|                                                          |
| [TRAILER ATT] [DASH MODE] [AUD PREV]  <- momentary       |
|                                                          |
| [RADIO KNOB]            [AUD PREV NEW][INFO NEW]         |
+----------------------------------------------------------+
```

Layouts A/B/C in 05-07 SVG files still show a CRUISE +/- rocker — they
need to be re-rendered with a cruise knob once the layout is chosen.

---

## 5. Open questions before build

1. Ignition key — does START spring back? How many contacts does it have?
2. Radio knob — does it have a push-to-click switch? (pause/play depends on it)
3. Are the wiper/light selectors OK with tap-counting, or should we try
   advanced controls.sii bindings instead?
4. Final keys must be verified against the actual ETS2 Controls menu.
5. Does the wiper selector have a spring-back "negative" position for
   Wipers Back? If not, Wipers Back needs its own momentary button
   (would push the matrix over 36 — need to free a position or add one).
6. Cruise knob — if it has a push, there is no free matrix position for
   it (matrix is 36/36). Skip the push or swap something out.
7. Confirm: 2 extra momentary buttons to buy (R6C5 = Momentary 9
   Infomaint, R6C6 = Momentary 10 spare). If the radio knob has no push,
   one more button is needed for pause/play.
8. Resolve the 5 key conflicts (see `10 - keyboard key inventory.md`)
   before writing firmware: P, SPACE, I, -, E.

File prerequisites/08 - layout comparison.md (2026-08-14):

# ETS2 Button Box — Panel Layout Comparison (v2)

Previous v1 layout rejected. Ignition key moved to bottom corner in all options.

Open the SVGs in a browser to compare:

- `05 - layout A - classic dash.svg`       — ignition bottom-LEFT
- `06 - layout B - split console.svg`      — ignition bottom-RIGHT
- `07 - layout C - cockpit cluster.svg`    — ignition bottom-LEFT

## Layout A — Classic Dash (ignition bottom-left)

```
FAR EDGE
[WIPERS] [LIGHTS]                    [RADIO]
[HB][BEA][HAZ] [DIFF][AXLE][CRUISE]
[PARK BRAKE][TRAILER BRAKE]  [WIN L][WIN R]
[CRUISE +/-]      [TRAILER ATT][DASH][AUD PREV]
[HORN][AIR][LT HORN][ACT][WIPER BACK]
[IGNITION]
FRONT EDGE
```

- Everything in tidy horizontal rows — easiest to build and label.
- Ignition tucked in the bottom-left corner, near the front edge, like
  reaching for a key while seated.
- Brakes sit in the middle of the panel — the most-grabbed controls stay
  central, horns at the front edge.

Pros: simplest panel to drill, symmetrical, classic layout.
Cons: a bit plain; lights and chassis toggles share one row.

## Layout B — Split Console (ignition bottom-right)

```
FAR EDGE
[WIPERS] [LIGHTS]                    [RADIO]
[HB][BEA][HAZ]        [DIFF][AXLE][CRUISE]
[WIN L][WIN R]        [PARK BRAKE][TRAILER BRAKE]
[CRUISE +/-]   [TRAILER ATT][DASH][AUD PREV]
[HORN][AIR][LT HORN][ACT][WIPER BACK]    [IGNITION]
FRONT EDGE
```

- Left half = CAB controls (lights, wipers, windows).
- Right half = CHASSIS + AUDIO (diff, axle, cruise, brakes, radio).
- Ignition in the bottom-right corner, mirror image of Layout A.

Pros: strong mental grouping — your left hand drives the cab, right hand
handles chassis/audio. Good if you drive right-handed with the mouse.
Cons: brakes are on the right side, away from the "default" left-hand
parking-brake reach.

## Layout C — Cockpit Cluster (ignition bottom-left)

```
FAR EDGE
[WIPERS] [LIGHTS]                    [RADIO]
[HB][BEA][HAZ]        [DIFF][AXLE][CRUISE]
[PARK BRAKE][TRAILER BRAKE] [WIN L][WIN R]
[CRUISE +/-]  [TRAILER ATT][DASH][AUD PREV]
[HORN][AIR][LT HORN][ACT][WIPER BACK]
[IGNITION]
FRONT EDGE
```

- Same parts as A but re-spaced: toggles split into two breathing groups,
  brakes pulled toward center, windows pushed to the right side.
- Ignition bottom-left.

Pros: more air between clusters, feels less crowded than A.
Cons: nearly identical layout to A — only worth it if you prefer the
spacing/grouping.

## Recommendation

Pick A if you want the cleanest build (simple drill pattern, easy labels).
Pick B if you want the cab/chassis mental split (left hand cab, right hand
chassis) — this is my favourite for driving ergonomics.

If you pick A or C, ignition stays bottom-left. If B, bottom-right.

## Checklist before cutting

1. Actual enclosure size (adjust spacing, not structure)
2. Push buttons plain or LED-ring (affects LED count)
3. Material + label method
4. Confirm ignition corner choice

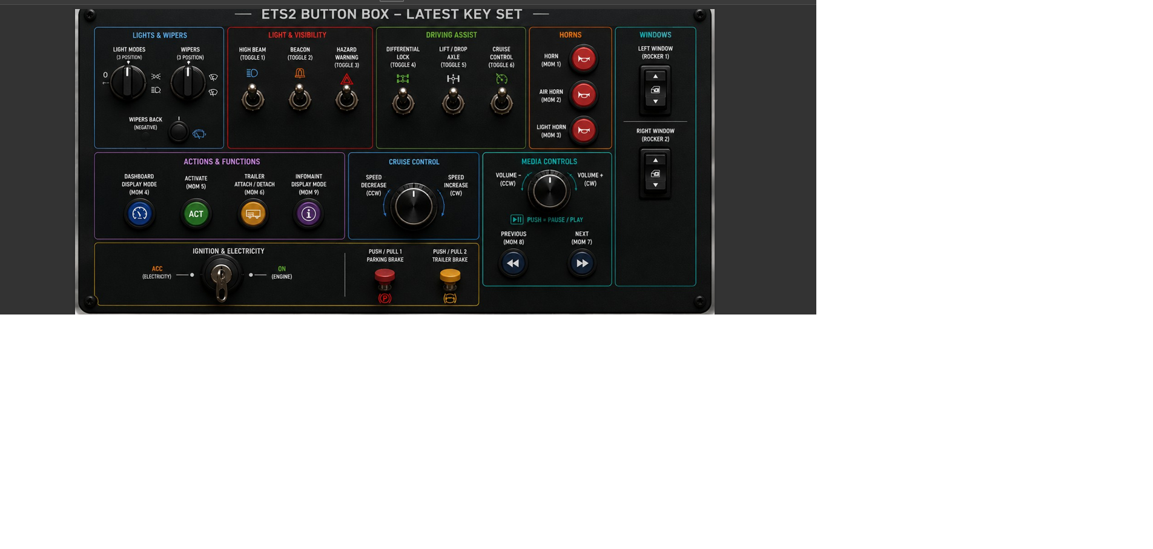
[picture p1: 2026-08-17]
genlayout.png

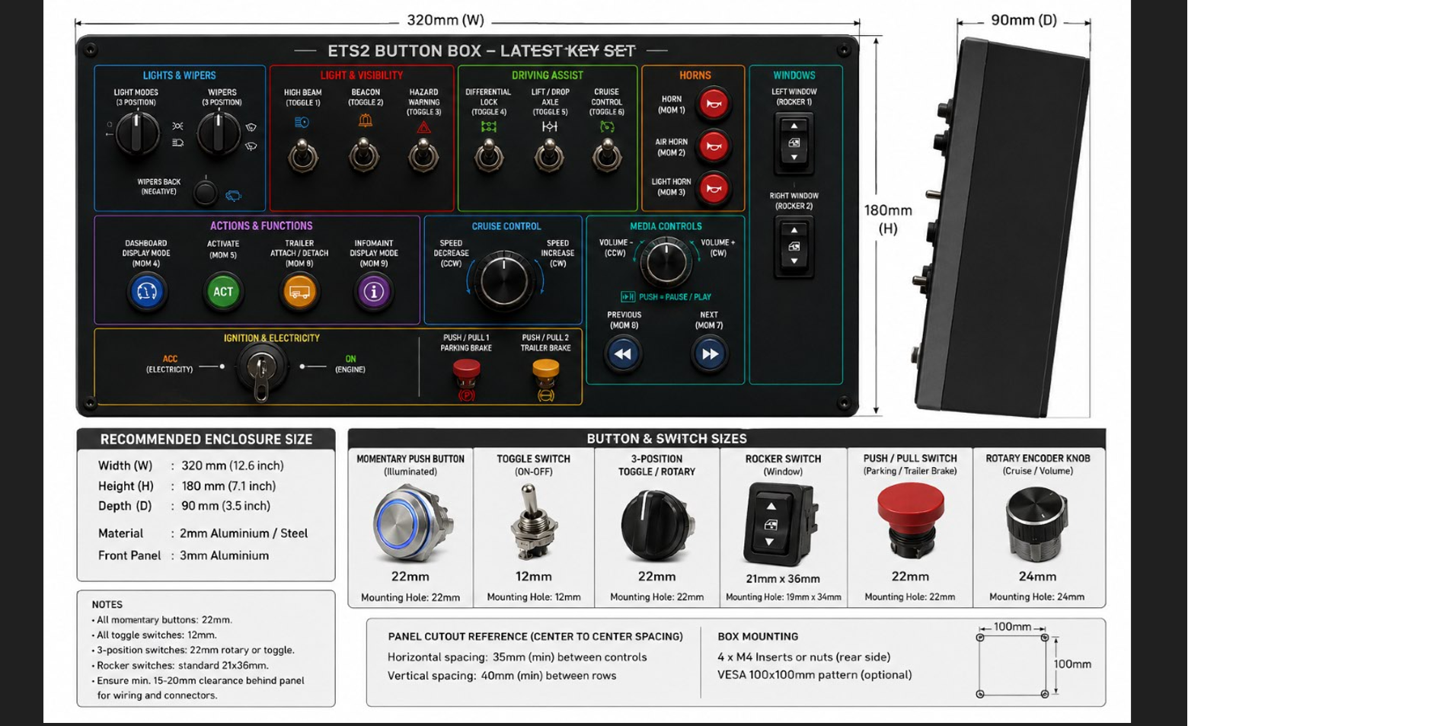
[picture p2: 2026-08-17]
prerequisites/layout mesaurment by chatgpy.png

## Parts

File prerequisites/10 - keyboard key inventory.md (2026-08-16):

# ETS2 Button Box — Keyboard Key Inventory

What keys the firmware must send, how many, and where each is used.

Source: `prerequisites/02 - mapping table.csv`
Status: PROPOSAL — all keys must be verified in the ETS2 Controls menu.

---

## 1. Summary

| Item | Count |
|---|---|
| ETS2 functions to bind | 31 |
| Distinct keys needed (after fixing conflicts below) | 30 |
| Keys currently suggested | 25 |
| Conflicts to fix (same key, different functions) | 5 |

Rule of thumb: in ETS2, ONE function = ONE key. The same key may be
reused only when it is literally the same function (e.g. the 3 wiper
selector positions all send the "Wipers" cycle key).

---

## 2. Full key list (what keys, used where)

| Key | ETS2 function | Matrix positions | OK? |
|---|---|---|---|
| P | Wipers (cycle) | R1C1, R1C2, R1C3 | CONFLICT with Audio Previous |
| L | Light modes (cycle) | R1C4, R1C5, R1C6 | OK |
| K | High Beam Headlights | R2C1 | OK |
| U | Beacon | R2C2 | OK |
| F | Hazard Warning | R2C3 | OK |
| D | Differential Lock | R2C4 | OK |
| J | Lift / Drop Axle | R2C5 | OK |
| C | Cruise Control | R2C6 | OK |
| SPACE | Parking Brake | R3C1 | CONFLICT with pause/play |
| 7 | Trailer Brake | R3C2 | OK |
| T | Trailer Attach / Detach | R3C3 | OK |
| N | Audio Player Next | R3C4 | OK |
| P | Audio Player Previous | R3C5 | CONFLICT with Wipers |
| H | Horn | R3C6 | OK |
| V | Air Horn | R4C1 | OK |
| B | Light Horn | R4C2 | OK |
| I | Dashboard Display Mode | R4C3 | CONFLICT with Infomaint |
| ENTER | Activate | R4C4 | OK |
| Q | Open Left Window | R4C5 | OK |
| A | Close Left Window | R4C6 | OK |
| W | Open Right Window | R5C1 | OK |
| S | Close Right Window | R5C2 | OK |
| = | Cruise Speed Increase | R5C3 | OK |
| - | Cruise Speed Decrease | R5C4 | CONFLICT with Volume Down |
| E | Engine Electricity | R6C2 | CONFLICT with Engine Start |
| E | Engine Start | R6C3 | CONFLICT with Engine Electricity |
| E | Engine crank (START) | R6C1 | shares key with Engine Start — OK |
| + | Audio Volume Up | R6C4 | OK |
| - | Audio Volume Down | R6C5 | CONFLICT with Cruise Decrease |
| SPACE | Audio pause/play | R6C6 | CONFLICT with Parking Brake |
| I | Infomaint display mode | R5C5 | CONFLICT with Dashboard |
| (spare) | - | R5C6 | - |

---

## 3. The 5 conflicts to fix

| # | Key | Function A | Function B | Suggested fix |
|---|---|---|---|---|
| 1 | P | Wipers | Audio Previous | Audio Previous -> 0 |
| 2 | SPACE | Parking Brake | Audio pause/play | pause/play -> 9 |
| 3 | I | Dashboard Display | Infomaint | Infomaint -> G |
| 4 | - | Cruise Decrease | Volume Down | Volume Down -> 8 |
| 5 | E | Engine Electricity | Engine Start | Electricity -> Shift+E (ETS2 default style) |

With these fixes the key map becomes:

| Key | Function |
|---|---|
| P | Wipers |
| L | Light modes |
| K | High Beam |
| U | Beacon |
| F | Hazard |
| D | Diff Lock |
| J | Axle |
| C | Cruise Control |
| SPACE | Parking Brake |
| 7 | Trailer Brake |
| T | Trailer Attach |
| N | Audio Next |
| 0 | Audio Previous |
| H | Horn |
| V | Air Horn |
| B | Light Horn |
| I | Dashboard Display |
| ENTER | Activate |
| Q / A | Left Window open / close |
| W / S | Right Window open / close |
| = / - | Cruise speed + / - |
| E | Engine Start (+ crank) |
| Shift+E | Engine Electricity |
| + / 8 | Volume up / down |
| 9 | pause/play |
| G | Infomaint |

Count: 30 distinct keys for 31 functions (crank shares Engine Start's key).

---

## 4. Verify checklist (in ETS2 Controls menu)

- [ ] Engine start/stop = E, engine electricity = Shift+E?
- [ ] Wipers = P, lights = L?
- [ ] High beam = K, beacon = U, hazard = F?
- [ ] Cruise = C, speed +/-, resume?
- [ ] Windows open/close = Q/A/W/S?
- [ ] Horn = H, air horn = V, light horn = B?
- [ ] Audio next/prev/vol/pause keys?
- [ ] Dashboard / Infomaint display keys?
- [ ] Trailer attach = T, park brake = SPACE, trailer brake = 7?

If any default differs, update `02 - mapping table.csv` and this file
together — the firmware key map is generated from that table.

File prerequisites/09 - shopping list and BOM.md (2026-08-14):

# ETS2 Button Box — Shopping List & Bill of Materials (BOM)

Everything needed for the build, split into:
1. Parts count at a glance
2. Already owned
3. To buy (electrical)
4. To buy (tools)
5. Decide later / optional

Quantities are based on the mapping in `01 - key to physical button mapping.md`.

---

## 0. Parts count at a glance

| # | Part | Qty |
|---|---|---|
| 1 | 3-position rotary selector | 2 |
| 2 | Toggle switch (on/off) | 6 |
| 3 | Push/pull switch | 2 |
| 4 | Rocker switch | 2 (3rd optional spare) |
| 5 | Momentary push button | 7 (5 owned + 2 to buy) |
| 6 | Latching push button (used as momentary) | 3 |
| 7 | Ignition key switch | 1 |
| 8 | Rotary encoder knob (EC11, with push for radio) | 2 (1 owned + 1 to buy) |
| 9 | 5 mm LED | 23 |
| 10 | 330 ohm resistor | 23+ |
| 11 | 0.1 uF capacitor | 3 |
| 12 | Raspberry Pi Pico H | 1 |
| 13 | 74HC595 breakout | 3 |

Total physical switch positions (matrix): 36 of 36 used.

---

## 1. Already owned — do NOT buy

| Qty | Item | Purpose |
|---|---|---|
| 1 | Raspberry Pi Pico H (RP2040, soldered headers) | Main brain |
| 3 | SmartElex 74HC595 shift register breakout | LED driver chain |
| 1 | Pro Micro (Type C, ATmega32U4) | Spare / test board |
| 2 | 3-position rotary selector | Wipers + Lights |
| 6 | Toggle switch (on/off) | High beam, beacon, hazard, diff lock, axle, cruise |
| 2 | Push/pull switch | Parking brake, trailer brake |
| 3 | Rocker switch (only 2 used) | Windows L/R + 1 spare |
| 3 | Latching push button | Momentary 6/7/8 bodies |
| 5 | Momentary push button | Horn, air horn, light horn, dashboard, activate |
| 1 | Ignition key switch | ACC / ON / START |
| 1 | Radio knob / encoder (EC11, if it clicks) | Volume + pause/play |
| 23 | 5 mm LEDs (assorted kit) | Indicator LEDs |
| 1 | Multimeter | Measuring selectors, continuity, testing |

---

## 2. To buy — electrical

| Qty | Item | Purpose / notes |
|---|---|---|
| 1 | EC11 rotary encoder with push button (cruise knob) | Cruise speed +/-, same as radio knob |
| 2 | Momentary push button (12 or 16 mm) | Momentary 9 (Infomaint) + 1 spare |
| 1 | Encoder knob cap (6 mm D-shaft, if not included) | Fits cruise knob |
| 23+ | Resistors 330 ohm (1/4 W) | One per LED; buy 50-pack, cheaper |
| 10+ | Resistors 100-150 ohm (1/4 W) | For blue/white LEDs at 3.3 V if too dim |
| 3 | Ceramic capacitor 0.1 uF | Decoupling next to each 74HC595 |
| 1 roll | Hookup wire, 22 AWG solid core | Matrix rows/columns, LEDs |
| 1 roll | Hookup wire, 22 AWG stranded | Flexible runs, jumpers |
| 1 | Heat-shrink tubing assortment | Insulating solder joints |
| 1 | 5V/3A USB power source (or use PC USB) | Pico power (3.3 V out for logic) |
| 1 | USB cable (USB-A/C to Pico Micro-USB) | Pico to PC |
| 10+ | Jumper wires male-male (dupont) | Breadboard testing phase |

Optional electrical (only if needed):
| Qty | Item | Purpose |
|---|---|---|
| 1 | Stripboard / protoboard (or perfboard) | Permanent soldered matrix instead of breadboard |
| 1 | Screw terminal block (e.g. 2x8) | Common ground bus + LED returns |
| 1 | 3D-printed / acrylic enclosure | Housing; decide with layout |
| 1 | Panel material (acrylic/aluminium/wood) | If no enclosure |

---

## 3. To buy — tools

| Qty | Item | Purpose |
|---|---|---|
| 1 | Soldering iron + solder (60/40 or lead-free) | Wiring the final build |
| 1 | Wire strippers + cutters | Prepping wire |
| 1 | Drill (or Dremel) | Mounting holes for switches |
| 1 set | Drill bits / step drill (3-22 mm) | 5 mm LEDs, 12 mm switches, 20 mm selectors |
| 1 | Digital caliper | Measuring hole centers, parts |
| 1 | Helping hands / third-hand tool | Soldering small assemblies |
| 1 | Multimeter (if not already owned) | Continuity + resistance checks |
| 1 | Screwdriver set (small Phillips + flat) | Mounting terminals, knobs |
| 1 | Hot glue gun + glue sticks | Cable relief, mounting LEDs |
| 1 | Desoldering pump / braid | Fixing mistakes |
| 1 | Small file / deburring tool | Cleaning drilled holes |

---

## 4. Decide later / optional

| Item | When |
|---|---|
| Enclosure + panel material | After choosing layout (A/B/C) |
| Panel labels (engraved/sticker/painted) | After layout + material choice |
| 3rd rocker (spare) | Only if panel has room |
| Extra EC11 knob caps (colored) | Cosmetic |
| Breadboard | Already part of test phase if you have one |

---

## Quick buy checklist (minimum to start building)

- [ ] 1x EC11 encoder (cruise knob)
- [ ] 2x momentary push button
- [ ] 50x 330 ohm resistors
- [ ] 10x 100-150 ohm resistors (blue/white LEDs)
- [ ] 3x 0.1 uF capacitors
- [ ] Wire: 22 AWG solid + stranded
- [ ] Heat-shrink assortment
- [ ] USB cable for Pico
- [ ] Soldering iron + solder
- [ ] Wire strippers
- [ ] Drill + step drill bits
- [ ] Digital caliper
- [ ] Helping hands

---

## Notes

- The 330 ohm starting value is per SOUL.md. At 3.3 V, blue/white LEDs
  (3.0-3.3 V forward voltage) may be dim — keep the 100-150 ohm pack handy.
- Matrix diodes (1N4148, ghosting protection) are SKIPPED by decision —
  the user does not expect to press many buttons simultaneously. If
  ghosting ever shows up, add them later (one diode per switch, 36 max).
- All quantities assume one button box. Double the resistor packs
  if you plan a second box later — bulk is cheaper.

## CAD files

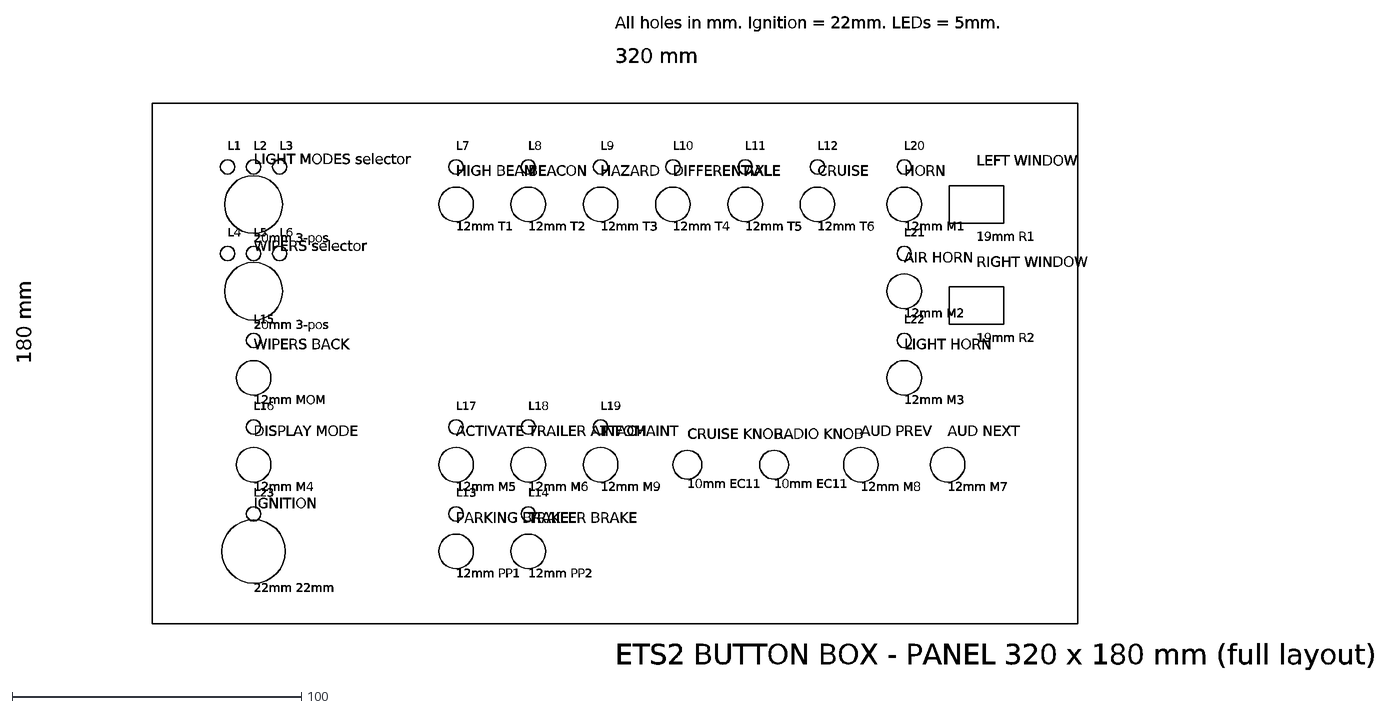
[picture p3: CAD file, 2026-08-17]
freecad/panel-320x180-full-layout.dxf
LIGHT MODES selector
20mm 3-pos
WIPERS selector
WIPERS BACK
12mm MOM
DISPLAY MODE
12mm M4
IGNITION
22mm 22mm
HIGH BEAM
12mm T1
BEACON
12mm T2
HAZARD
12mm T3
DIFFERENTIAL
12mm T4
AXLE
12mm T5
CRUISE
12mm T6
HORN
12mm M1
AIR HORN
12mm M2
LIGHT HORN
12mm M3
LEFT WINDOW
19mm R1
RIGHT WINDOW
19mm R2
ACTIVATE
12mm M5
TRAILER ATTACH
12mm M6
INFOMAINT
12mm M9
CRUISE KNOB
10mm EC11
RADIO KNOB
AUD PREV
12mm M8
AUD NEXT
12mm M7
PARKING BRAKE
12mm PP1
TRAILER BRAKE
12mm PP2
L1
L2
L3
L4
L5
L6
L7
L8
L9
L10
L11
L12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

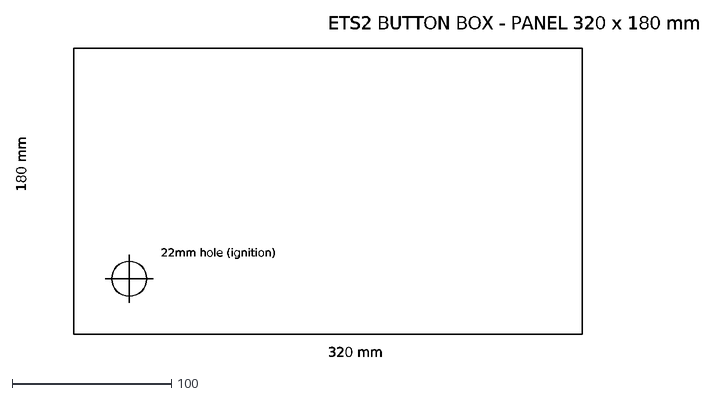
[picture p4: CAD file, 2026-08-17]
freecad/panel-320x180-22mm-hole.dxf
ETS2 BUTTON BOX - PANEL 320 x 180 mm
22mm hole (ignition)
320 mm
180 mm

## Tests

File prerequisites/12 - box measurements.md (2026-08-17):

# ETS2 Button Box — Box & Panel Measurements

Measurements derived from the chosen layout (`genlayout.png` — "LATEST KEY
SET") and the hole-size conventions in `03 - panel layout design.md`.

Companion file: `13 - drilling template.svg` — printable 1:1 template with
every hole center marked (mm from top-left). Print at 100% scale, no scaling.

---

## 1. Panel outer size

| Dimension | Value |
|---|---|
| Width | 650 mm |
| Height | 342 mm |
| Aspect | ~1.9 : 1 landscape |
| Suggested material | 4-6 mm acrylic / aluminium / wood panel |
| Edge margin | 25 mm around all controls |

Orientation: TOP edge = far edge (display side), BOTTOM edge = front edge
toward the user. Ignition key sits at the bottom-LEFT corner, brakes on the
bottom row — matches the chosen layout.

---

## 2. Hole sizes (drill chart)

| Control | Qty | Hole / cutout |
|---|---:|---|
| 3-position rotary selector | 2 | 20 mm round |
| Toggle switch | 6 | 12 mm round |
| Push/pull switch | 2 | 12 mm round |
| Rocker switch | 2 | 19 x 13 mm rectangle |
| Momentary push button | 7 | 12 mm round (16 mm if LED-ring) |
| Latching button (as momentary) | 3 | 12 mm round (16 mm if LED-ring) |
| Ignition key switch | 1 | 19 mm round (up to 22 mm for the key barrel) |
| EC11 encoder (cruise, radio) | 2 | 10 mm round (6 mm shaft) |
| Indicator LED | 23 | 5 mm round |

Spacing rule satisfied: every control center is >= 25 mm from every other
center (verified programmatically). Finger/knob collisions are avoided.

---

## 3. Control hole centers (mm from panel top-left)

Coordinates are the CENTER of each hole. X grows right, Y grows down
(toward the user).

| Control | X | Y | Hole |
|---|---:|---:|---|
| LIGHT MODES selector | 35 | 48 | 20 round |
| WIPERS selector | 35 | 113 | 20 round |
| WIPERS BACK | 35 | 178 | 12 round |
| DISPLAY MODE (M4) | 35 | 233 | 12 round |
| IGNITION | 35 | 308 | 19 round |
| HIGH BEAM (T1) | 130 | 48 | 12 round |
| BEACON (T2) | 185 | 48 | 12 round |
| HAZARD (T3) | 240 | 48 | 12 round |
| DIFFERENTIAL (T4) | 295 | 48 | 12 round |
| AXLE (T5) | 350 | 48 | 12 round |
| CRUISE (T6) | 405 | 48 | 12 round |
| HORN (M1) | 530 | 48 | 12 round |
| AIR HORN (M2) | 530 | 113 | 12 round |
| LIGHT HORN (M3) | 530 | 178 | 12 round |
| LEFT WINDOW (R1) | 615 | 48 | 19 x 13 rect |
| RIGHT WINDOW (R2) | 615 | 123 | 19 x 13 rect |
| ACTIVATE (M5) | 130 | 233 | 12 round |
| TRAILER ATTACH (M6) | 185 | 233 | 12 round |
| INFOMAINT (M9) | 240 | 233 | 12 round |
| CRUISE KNOB (EC11) | 315 | 233 | 10 round |
| RADIO KNOB (EC11) | 400 | 233 | 10 round |
| AUD PREV (M8) | 465 | 233 | 12 round |
| AUD NEXT (M7) | 520 | 233 | 12 round |
| PARKING BRAKE (PP1) | 195 | 308 | 12 round |
| TRAILER BRAKE (PP2) | 260 | 308 | 12 round |

---

## 4. LED hole centers (5 mm)

LEDs sit 15 mm above their control (or beside, for brakes/ignition).

| LED # | Function | X | Y |
|---|---:|---|---:|---:|
| 1 | Wiper LEFT | 25 | 33 |
| 2 | Wiper CENTER | 35 | 33 |
| 3 | Wiper RIGHT | 45 | 33 |
| 4 | Lights state 1 | 25 | 98 |
| 5 | Lights state 2 | 35 | 98 |
| 6 | Lights state 3 | 45 | 98 |
| 7 | High beam | 130 | 28 |
| 8 | Beacon | 185 | 28 |
| 9 | Hazard | 240 | 28 |
| 10 | Diff lock | 295 | 28 |
| 11 | Axle | 350 | 28 |
| 12 | Cruise | 405 | 28 |
| 13 | Park brake | 180 | 293 |
| 14 | Trailer brake | 245 | 293 |
| 15 | Wipers back | 35 | 158 |
| 16 | Display mode | 35 | 213 |
| 17 | Activate | 130 | 213 |
| 18 | Trailer attach | 185 | 213 |
| 19 | Infomaint | 240 | 213 |
| 20 | Horn | 530 | 28 |
| 21 | Air horn | 530 | 93 |
| 22 | Light horn | 530 | 158 |
| 23 | Ignition | 35 | 288 |

Total: 23 LEDs = 3x 74HC595 capacity (24 outputs, 1 spare).

---

## 5. Box depth / enclosure

| Component | Depth needed |
|---|---|
| Toggle / push button body | ~20-30 mm behind panel |
| 74HC595 breakouts + wiring | ~15-20 mm |
| Pico H | ~15 mm |
| Total internal depth | ~50-60 mm |

Suggested enclosure: panel + box of 60-80 mm internal depth, with 3-5 mm
standoffs for the Pico and 74HC595 boards. Add cable exit at the back or
bottom.

---

## 6. How to use the drilling template

1. Print `13 - drilling template.svg` at 100% scale (check printer scaling
   is OFF).
2. Confirm the printed panel outline measures exactly 650 x 342 mm.
3. Tape the print to the panel material.
4. Center-punch each red circle/rectangle.
5. Drill: pilot holes first, then step-drill to final size
   (5 / 10 / 12 / 19-20 mm; rockers need a 19 x 13 mm slot — drill two
   13 mm holes at the ends and file/jigsaw between).
6. LEDs are the orange circles (5 mm).
7. All coordinates in the tables above are mm from the panel top-left —
   measure twice, drill once.

---

## 7. Open questions

1. Do the momentary buttons have LED rings (16 mm) or plain (12 mm)?
   Affects those hole sizes.
2. Panel material and thickness (acrylic / aluminium / wood / 3D print)?
3. Ignition key barrel diameter — 19 or 22 mm? Measure before drilling.
4. Enclosure: 3D printed box, ready-made project box, or wood frame?
5. Want the panel scaled down (e.g. 500 mm wide) if 650 mm is too big
   for the desk? All coordinates scale linearly.

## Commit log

2026-08-10 Initial commit: project scaffold from SOUL.md spec
    - SOUL.md: full project spec (GPIO map, 6x6 matrix map, LED plan, behavior rules)
    - README.md: repo overview and layout
    - .gitignore: Arduino build artifacts, editor junk
    - firmware/: sketch folders placeholder (usb_keyboard_test first up)
    - docs/: wiring, ETS2 bindings, selector measurements placeholders
2026-08-14 Add prerequisites: key mapping, panel layouts, ETS2 bindings reference
    - Map all 29 ETS2 functions from keys.txt to physical controls (matrix map)
    - Add 3 alternative panel layouts (SVG) with ignition key at bottom corner
    - Add layout comparison doc and LED placement plan
    - Include ETS2 control name reference (xlsx) and gitignore for lock files
    [02 - mapping table.csv, ATS and ETS2 Key Bindings.xlsx]
2026-08-14 Update README: hardware inventory, prerequisites index, current status
2026-08-14 Update mapping: add Audio pause/play and Infomaint display mode
    - 2 new functions from updated keys.txt map to spare matrix positions R6C5/R6C6
    - Note: these need 2 extra physical buttons (or reshuffle radio knob push)
    [02 - mapping table.csv]
2026-08-14 Record decision: 2 extra momentary buttons to be purchased for R6C5/R6C6
2026-08-14 Update mapping: cruise speed on second encoder knob, audio reassignments
    - Cruise Control stays on Toggle 6; speed +/- moved from Rocker 3 to a
    second EC11 encoder knob (R5C3/R5C4)
    - Radio knob push now = Audio pause/play (user edit)
    - Audio Next -> Momentary 5, Audio Previous -> NEW button 1, Infomaint -> NEW button 2
    - Wipers Back moved to wiper selector negative position (pending confirmation)
    - Matrix now fully used (36/36)
    [02 - mapping table.csv]
2026-08-14 Sync mapping tables with user coverage edits
    - Renumber momentaries 1-9: Dashboard Display -> M4, Activate -> M5,
    Trailer Attach -> M6, Audio Next -> M7, Audio Previous -> M8,
    Infomaint -> M9
    - Latching buttons repurposed as momentary-style (one tap per press)
    - Inventory, layout sketch, open questions, and CSV updated to match
    [02 - mapping table.csv]
2026-08-14 Add shopping list / bill of materials (owned, to buy, tools)
2026-08-14 Skip matrix diodes by decision; update BOM and SOUL.md
    User does not expect simultaneous multi-button presses. Diodes removed
    from shopping list; add later only if ghosting appears in testing.
2026-08-14 Add parts count at a glance to BOM
2026-08-16 Add matrix design; re-map ignition onto row 6 for single-common key
    [02 - mapping table.csv]
2026-08-17 Add box measurements and 1:1 drilling template from chosen layout
2026-08-17 Add FreeCAD DXF: 320x180mm panel with 22mm ignition hole
    [panel-320x180-22mm-hole.dxf]
2026-08-17 Add full control layout DXF fitted to 320x180mm panel (25 holes + 23 LEDs)
    [panel-320x180-full-layout.dxf]
